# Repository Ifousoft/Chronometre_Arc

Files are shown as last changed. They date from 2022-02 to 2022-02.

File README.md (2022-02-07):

# Chronometre_Arc
Chronomètre de tir à l'arc

Ce chronomètre permet l’entraînement des archers à la compétition. Le chronomètre permet de choisir les équipes A/B ou C/D ainsi que de configurer les durées de pré-tir et de tir. Le chronomètre déclenche la sonnerie de pré-tir et de tir. La télécommande fournie avec le chronomètre permet de configurer les paramètres du chronomètre, de lancer le tir, de mettre le tir en pause ou de stopper le tir.
Les fichiers pour le code du chronomètre ainsi que la télécomande sont fournis.
Le modèle 3D pour le télécommande est également fourni au format Fusion 360.
Les plans électroniques pour la carte du chronomètre et celle de la télécommande sont fournis.

Coût d'environs 200 euros pour la partie électronique.

Le chronomètre est constitué de 3 écrans LED 64x32 pour avoir une des chiffres de 12 cm de haut. Les trois écrans sont installés verticalement.
Le chronomètre est piloté par un ESP32 et connecté à la télécommande en LoRa pour une grande portée.
La télécommande fonctionne avec un arduino nano et une puce LoRa.

Attention, erreur de conception, l'ampli est connecté sur une pate de l'esp32 qui n'est pas prévue pour passer un son mp3 ce qui rend impossible de jouer une musique.
Les sons pour démarrer ou stopper le tir ne sont donc pas très agréables.

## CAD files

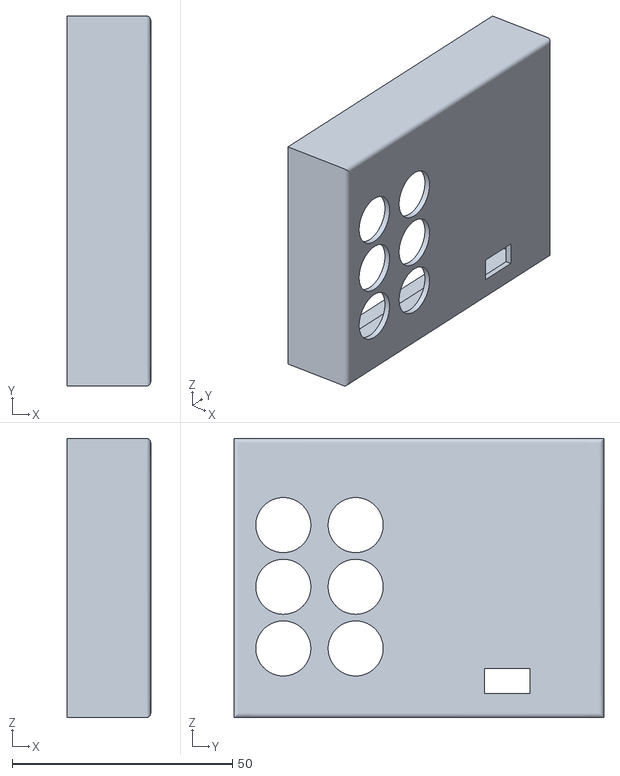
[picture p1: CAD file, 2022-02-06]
3D_models/Dessus.stl
19.0 x 84.0 x 63.4

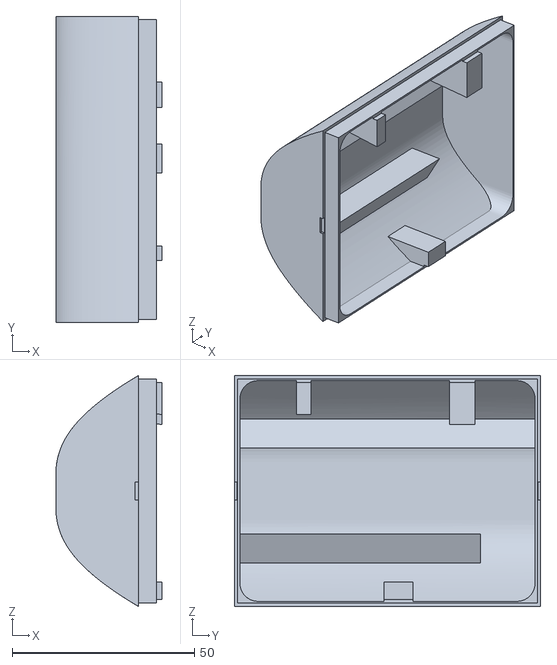
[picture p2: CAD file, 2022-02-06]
3D_models/Fond_V4.stl
29.2 x 84.0 x 63.4

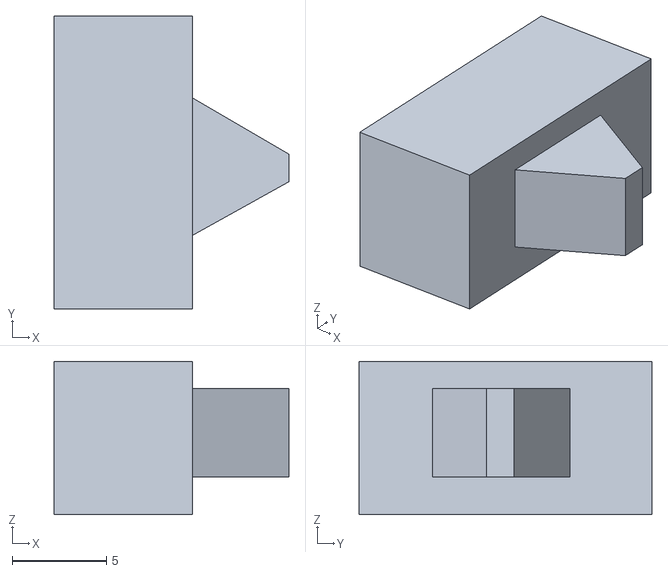
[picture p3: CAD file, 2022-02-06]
3D_models/Tirette.stl
12.5 x 15.6 x 8.15

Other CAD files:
3D_models/Telecomande_ARC_courbe v5.f3d

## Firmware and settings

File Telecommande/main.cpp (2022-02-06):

/*
Test Lora - Recepteur Télécommande ARC
06/10/2020
Heart beat: 39 mA
Sleep: 22,4 mA
Send Lora: 50 mA
Capacité pilr R6 2500 mA
Ecran OLED, serait en moyenne a 450 uA en fonctionnement
Antenne Lora en SPI (MISO/MOSI)

Voltage
3,27 bug
3,3 bug3,51 ok
3,55 bug

AFAIRE:
- Gestion de la batterie...
- Lorsque la télécommande se signale à l'écran: attendre un retour
- Est-ce nécessaire de réduire la vitesse du bus SPI ?
- Attendre un retour lors de l'envoie d'un message
- enableCRC
*/

/* PROTOCOLE
ENVOI DU BOUTON:
- Premier octet: numéro de l'émetteur (22 pour la télécommande ou 33 pour le heart beat de la télécommande)
- Deuxième octet: numéro du message cyclique de 0 à 7
- Troisième octet: numéro du bouton
ACK:
- premier octet: numéro de l'émetteur (22 ou 33)
- second octet: numéro du message reçu
HEART BEAT: Envoi périodique d'une pulsation à l'écran. En cas de problème l'écran affiche et la télécommande clignote
- premier octet: numéro de l'émetteur 33 pour heart beat
- second octet: numéro cyclique de 0 à 7

- Clignotement rapide LED power: low batt
*/

#define DEBUG // si défini = on affiche sur Serial, sinon riens

#include <Arduino.h>

#include <SPI.h>
#include <LoRa.h>
#include <avr/sleep.h>
#include <avr/power.h>
//#include <MsTimer2.h>
#include <avr/wdt.h>

#define SLEEP_PIN 3
#define FALSE  0
#define TRUE !FALSE

// Boutons ligne haut MOINS - SELECT - PLUS
// Boutons ligne bas START - STOP - PAUSE
#define PIN_BOUTON_PLUS A7 // Analogique
#define PIN_BOUTON_MOINS  8
#define PIN_BOUTON_SELECT 7

#define PIN_BOUTON_STOP 5
#define PIN_BOUTON_PAUSE  6     // Analogique
#define PIN_BOUTON_START  4


#define LED_LORA  A5 // Analogique
#define LED_POWER A2 // Analogique
#define PIN_VOLTAGE A0

#define VOLTAGE_LIMIT 3.3

// Attention, définition des boutons commun avec les recepteurs !
#define LORA_BOUTON_PLUS    1
#define LORA_BOUTON_MOINS   2
#define LORA_BOUTON_SELECT  3
#define LORA_BOUTON_INIT    4
#define LORA_BOUTON_STOP    5
#define LORA_BOUTON_PAUSE   6
#define LORA_BOUTON_START   7
#define LORA_HEART_BEAT     33  // Dites "33"...

#define ID_SENDER 22  // Pourquoi pas ?
#define ID_HEART_BEAT 33  // Pourquoi pas ?
#define NB_HEART_BEAT  4  // Nombre d'attente de 8 secondes de watchdog avant d'envoyer une pulsation

byte Id_Message = 0; // Sera incrémenté de 0 à 7
byte Id_Heart_Beat = 0;

byte Nb_Heart_Beat = NB_HEART_BEAT; 

byte Ack_Recu = FALSE;
byte Low_Batt = FALSE;

#define ATTENTE_ACK 3000  // Attente max pour un ACK en ms

// LORA pins
const int csPin = 10;          // 10 normalement 7 LoRa radio chip select
const int resetPin = 9;       // 5 d'après mon shéma... 6 LoRa radio reset
const int irqPin = 2;         // 1 DIO0 change for your board; must be a hardware interrupt pin

byte Bouton = 0;
unsigned int Rebond = 0;

void SendLoraMsg( byte bouton );
void InterruptionSendHeartBeat( void );

/********************************
 * watchdog interrupt
 * 
 * Appelé par le watchdog à la fin du timer
 * 
 * ******************************/
ISR (WDT_vect) 
{
   wdt_disable();  // disable watchdog

}  // end of WDT_vect

/********************************
 * SendHeartBeat
 * 
 * Envoi une pulsation à l'écran
 * 
 * ******************************/
void SendHeartBeat( void )
{
  SendLoraMsg( LORA_HEART_BEAT );
#ifdef DEBUG 
  Serial.println( "---- Hear Beat ----");
#endif
  analogWrite( LED_POWER, 255 );
  delay( 100 );
  analogWrite( LED_POWER, 0 );

} /* End of SendHeartBeat */

/******************************
 * WakeUp
 * 
 * Appellee en cas de reveil. Positionne Bouton à la valeur du bouton appuyé
 * 
 * *****************************/
void WakeUp( void )
{
  if( millis() + 100 > Rebond )
  {
    //Serial.print( "Reveil ");
    Bouton = 0;
    if( analogRead(PIN_BOUTON_PLUS) > 800  )
      Bouton = LORA_BOUTON_PLUS;
    else
    {
      if( digitalRead(PIN_BOUTON_MOINS) == 1 )
        Bouton = LORA_BOUTON_MOINS;
      else
      {
        if( digitalRead(PIN_BOUTON_SELECT) == 1 )
          Bouton = LORA_BOUTON_SELECT;
        else
        {
          if( digitalRead(PIN_BOUTON_STOP) == 1 )
            Bouton = LORA_BOUTON_STOP;
          else
          {
            if( digitalRead( PIN_BOUTON_START) == 1 )
              Bouton = LORA_BOUTON_START;
            else
            {
              if( digitalRead( PIN_BOUTON_PAUSE ) == 1 )
                Bouton = LORA_BOUTON_PAUSE;
            } /* End of if */           
          } /* End of if */
        } /* End of if */
      } /* End of if */
    } /* End of if */

#ifdef DEBUG
    if( Bouton != 0 )
    {
      Serial.print( "****** Bouton =" );
      Serial.println( Bouton );
    } /* End of if */
#endif
    Rebond = millis();
  } /* End of if */

} /* End of WakeUp */

/**************************************
 * RecoitAck
 * 
 * Call back en cas de reception de la part de l'écran: ACK ou HEART BEAT
 * 
 * Positionne une variable globale si ACK et/ou si HEART BEAT
 * 
 * ***************************************/
void RecoitAck(int packetSize)
{
  if (packetSize == 2)
  {
    byte id_sender_back;
    byte id_message_back;

    id_sender_back = LoRa.read();
    id_message_back = LoRa.read();

    if( id_sender_back == ID_SENDER && id_message_back == Id_Message )
    {
      Ack_Recu = TRUE;
      Id_Message = (Id_Message +1 ) % 8;
#ifdef DEBUG
      Serial.println( "ACK correct recu ............");
#endif
      analogWrite( LED_LORA, 1024 );
      delay( 50 );
      analogWrite( LED_LORA, 0 );
    }
#ifdef DEBUG
    else
    {
      Serial.println( "ERREUR - ACK correct mais pour un mauvais message ");
    }
#endif  
  }
#ifdef DEBUG
  else
  {
    Serial.println( "ERREUR - ACK de taille incorrecte ");
  }
#endif  
} /* End of RecoitAck */

/****************************
 * 
 * SendLoraMsg
 * 
 * Envoie le message en LORA et attend le ACK
 * 
 * *************************/
void SendLoraMsg( byte bouton )
{
  LoRa.beginPacket();
  LoRa.write( ID_SENDER );
  LoRa.write( Id_Message );
  LoRa.write( bouton );
  LoRa.endPacket();
#ifdef DEBUG
  Serial.print( "LoRa sent: ");
  Serial.println( bouton );
#endif
  analogWrite( LED_LORA, 1024 );
  delay( 50 );
  analogWrite( LED_LORA, 0 );

} /* End of SendLoraMsg */

/************************
 * InitTelecommandeVersEcran
 * 
 * Signale la télécommande à l'écran
 * 
 * **************************/
void InitTelecommandeVersEcran( void )
{
  SendLoraMsg( LORA_BOUTON_INIT );
  analogWrite( LED_POWER, 1024 );
  delay( 100 );
  analogWrite( LED_POWER, 0 );
  delay( 100 );
  analogWrite( LED_POWER, 1024 );
  delay( 100 );
  analogWrite( LED_POWER, 0 );

} /* End of InitTelecommandeVersEcran */

/*******************************
 * StartLoRa
 * 
 * Démarre ou reveille la puce lora pour préparer la transmission
 * 
 * *****************************/
void StartLoRa( void )
{
#ifdef DEBUG
  Serial.println("*********** Debut LORA Begin");
#endif
  while( !LoRa.begin(868E6) )
  {
#ifdef DEBUG
    Serial.println("Starting LoRa...");
#endif
    delay( 500 );
  }
#ifdef DEBUG
  Serial.println(" LORA Begin success");
#endif

} /* End of StartLoRa */

/******************************
 * SetWatchDog
 * 
 * Arme un timer de 8 secondes maximum pour le reveiller
 * 
 * *****************************/
void SetWatchDog( void )
{
  // WatchDog toutes les 8 secondes
    // clear various "reset" flags
  MCUSR = 0;     
  // allow changes, disable reset
  WDTCSR = bit (WDCE) | bit (WDE);
  // set interrupt mode and an interval 
  WDTCSR = bit (WDIE) | bit (WDP3) | bit (WDP0);    // set WDIE, and 8 seconds delay
  wdt_reset();  // pat the dog

} /* End of SetWatchDog */

/***************************
 * setup
 * 
 * *************************/
void setup( void ) {

#ifdef DEBUG
  Serial.begin(115200);
  Serial.println(" Démarrage.");
#endif
  pinMode( PIN_BOUTON_PLUS, INPUT );
  pinMode( PIN_BOUTON_MOINS, INPUT );
  pinMode( PIN_BOUTON_SELECT, INPUT );
  pinMode( PIN_BOUTON_STOP, INPUT );
  pinMode( PIN_BOUTON_START, INPUT );
  pinMode( PIN_BOUTON_PAUSE, INPUT );
  pinMode( PIN_VOLTAGE, INPUT );

  pinMode( LED_LORA, OUTPUT );
  pinMode( LED_POWER, OUTPUT );

  for( byte i = 0 ; i < 5 ; i ++ )
  {
    analogWrite( LED_LORA, 1024 );
    delay( 150 );
    analogWrite( LED_LORA, 0 );
    delay( 150 );
  }

  // Sleep
  // Serial.end();
  pinMode( SLEEP_PIN, INPUT);
  sleep_enable();
//  power_adc_disable();
//  power_spi_disable(); Utile pour LORA
// power_timer0_disable();
// power_timer1_disable();
 power_timer2_disable();
  attachInterrupt(1, WakeUp, HIGH); // Reveil sur la pate 4 (Interuption 1)
  set_sleep_mode (SLEEP_MODE_STANDBY);
//  set_sleep_mode (SLEEP_MODE_PWR_DOWN);

#ifdef DEBUG
  Serial.println("LoRa Sender");
#endif
  LoRa.setPins(csPin, resetPin, irqPin);// set CS, reset, IRQ pin
  LoRa.setSPIFrequency(1E6); // Ajout IFOU

  StartLoRa();

  LoRa.onReceive( RecoitAck );
  LoRa.receive();

  SetWatchDog();

  InitTelecommandeVersEcran();

} /* End of setup */

/**********************
 * BlynkBatt
 * 
 * Fait clignoter la LED power
 * 
 * *********************/
void BlynkBatt( void )
{
  for( byte i = 0 ; i < 5 ; i ++)
  {
    digitalWrite( LED_POWER, HIGH );
    delay(50);
    digitalWrite( LED_POWER, LOW );
    delay(50);
  } /* End of for */

} /* End of BlynkBatt */

/**************************
 * 
 * loop
 * 
 * *************************/
void loop() {

#ifdef DEBUG
  Serial.println( "Sleep activé");
  Serial.flush();
#endif
  LoRa.sleep();
  delay( 100 );
  sleep_cpu ();
#ifdef DEBUG
  Serial.println( "WakeUp");
#endif  
  // Au reveil, on s'annonce toujours vivant
  if( --Nb_Heart_Beat == 0 )
  {
    SendHeartBeat();
    Nb_Heart_Beat = NB_HEART_BEAT;
  } /* End of if */

  if( Bouton != 0)
    SendLoraMsg( Bouton );

#ifdef DEBUG
  Serial.print( "Voltage = ");
  Serial.println( analogRead( PIN_VOLTAGE ));
  float batt_level = analogRead( PIN_VOLTAGE )/1024.0*3.7;
  Serial.println( batt_level );
#endif
  if( batt_level < VOLTAGE_LIMIT )
    Low_Batt = TRUE;

  if( Low_Batt )
    BlynkBatt();

  LoRa.receive();
  //delay(1500);

  // On réarme le watchDog avant de se réendormir
  SetWatchDog();

} /* End of loop */

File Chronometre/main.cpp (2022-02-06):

// Chrono Arc V4 - LoRa
// 5 septembre Initialisation 2019
// 4 octobre réduction des chiffres pour passer sur 3 écrans avec 240 au max
// 29 novembre:
//    - affichage logo lora (bluetooth) en attente de télécommande
//    - On peut plus faire start qd on est en cours de chrono
//    - affichage de perte et de retour de télécommande
// 5 janvier 2021 - ajout de la possibilité d'utiliser les écrans extérieurs. Ca marche !
// 6 janvier 2021 - Ajout d'un flush après réception pour éviter les parasites
// 7 janvier 2021 - Ajout de la gestion de la luminosité pour écran extérieur (même pour int même si ca fait rien)
// 23 janvier 2021 - Réduction du nombre de raffraichissement pour accelerer affichage
// 6 décembre 2021 - Suppression du bruit parasite généré par l'initialisation de l'écran LED. Pas compris...
// 7 décembre 2021 - Impossible de lancer un Wav, il faudrait que les HP soient branchés sur le DAC pin 25 ou 26...
// 8 décembre 2021 - Affichage logo IfouSoft et Logo companie
// 10 décembre 2021 - Affichage du temps de tir avant la volée au lieu de la durée de pre-tir
//                  - Ajout d'une phase de PRE_VOLEE 

// A FAIRE
// Test de tout les éléments d'affichages au démarrage
// Le HP grésille légèrement (Qualité montage ?)
//    Mettre à bas le signal au démarrage ?
// Virer Blynk et remplacer ses timers
// Changer la couleur du pretir pour identifier la différence TIR/Pretir
//    Jean-Philippe ?
// Afficher logo de l'abbaye au démarrage ?

/*
A Faire:
P2 - Quand la télécommande est alluméé avant l'écran, un appuie sur un bouton devrait la faire reconnaitre par l'écran sans attendre le HeartBeat
- Reglable de la luminosité
P2 - descendre le defaut telecommande d'un cran
- Ajouter affichage indication pb batteries sur écran
- Afficher la durée du tir et non du prétir au démarrage
*/

// Choisir entre compiler pour écran intérieurs ou écran extérieur. Exclusifs
//#define ECRAN_INT   // Pour les écrans intérieurs utilisant la library EPS32 64x32 LED MATRIX HUB75 DMA Display
#define ECRAN_EXT   // Pour les ecran extérieurs ayant besoin de la library SmartMatrix pour remapper les lignes

#define VERSION "V4.0"


#include <Arduino.h>
#include <Wire.h>
#include <SPI.h>
#ifdef ECRAN_INT
#include <ESP32-RGB64x32MatrixPanel-I2S-DMA.h>
#else
#include <MatrixHardware_ESP32_V0.h>                // This file contains multiple ESP32 hardware configurations, edit the file to define GPIOPINOUT (or add #define GPIOPINOUT with a hardcoded number before this #include)
#include <SmartMatrix.h>
#endif
#include <BlynkSimpleEsp32_BT.h>
#include <Tone32.h>
#include "SPIFFS.h"

//#include "Abbaye.c"
#include "A1.c"
#include "A3.c"
#include "A2.c"
#include "Logo.ifou.c"

#define BUZZER_PIN 4 // 14 initialement mais changer et mettre ?
#define BUZZER_CHANNEL 0


#define DUREE_SECONDE 1000  // 1 seconde = 1000 ms
#define DUREE_AFFICHAGE_LOGO_IFOU 5000
#define DUREE_AFFICHAGE_LOGO_CIE 10000



#define BLYNK_USE_DIRECT_CONNECT

char auth[] = "y6KFaS2UmRR15rvGpoEeqGNoRn9UKU3E"; // Code de l'application Blynk

#ifdef ECRAN_INT
RGB64x32MatrixPanel_I2S_DMA dma_display;

#define COULEUR_ROUGE dma_display.color444(15, 0, 0)
#define COULEUR_VERT  dma_display.color444(0, 15, 0)
#define COULEUR_BLEU  dma_display.color444(0, 0, 15)
#define COULEUR_NOIR  dma_display.color444(0, 0, 0)
#define COULEUR_BLANC dma_display.color444(15, 15, 15)
#define COULEUR_ORANGE  dma_display.color444(15, 9, 0)
#define COULEUR_IFOU  dma_display.color444(2, 2, 7)
#define COULEUR_JAUNE  dma_display.color444(15, 15, 0)
#else
#define COLOR_DEPTH 24                  // known working: 24, 48 - If the sketch uses type `rgb24` directly, COLOR_DEPTH must be 24

const uint8_t kMatrixWidth = 192;        // 32 known working: 16, 32, 48, 64
const uint8_t kMatrixHeight = 32;       // 16 known working: 32, 64, 96, 128
const uint8_t kPanelType = SM_PANELTYPE_HUB75_32ROW_64COL_MOD8SCAN_IFOU;   // use SMARTMATRIX_HUB75_16ROW_MOD8SCAN for common 16x32 panels
const uint8_t kRefreshDepth = 36;       // known working: 24, 36, 48
const uint8_t kDmaBufferRows = 4;       // known working: 2-4, use 2 to save memory, more to keep from dropping frames and automatically lowering refresh rate
const uint8_t kMatrixOptions = (SMARTMATRIX_OPTIONS_NONE);      // see http://docs.pixelmatix.com/SmartMatrix for options
const uint8_t kBackgroundLayerOptions = (SM_BACKGROUND_OPTIONS_NONE);
const uint8_t kIndexedLayerOptions = (SM_INDEXED_OPTIONS_NONE);

const rgb24 COULEUR_NOIR = { 0, 0, 0 };
const rgb24 COULEUR_BLANC = { 255, 255, 255 };
const rgb24 COULEUR_ROUGE = { 255, 0, 0 };
const rgb24 COULEUR_VERT = { 0, 255, 0 };
const rgb24 COULEUR_BLEU = { 0, 0, 255 };
const rgb24 COULEUR_ORANGE = { 255, 165, 0 };
const rgb24 COULEUR_JAUNE = { 255, 255, 0 };
const rgb24 COULEUR_IFOU = { 34, 34, 127 };

SMARTMATRIX_ALLOCATE_BUFFERS(matrix, kMatrixWidth, kMatrixHeight, kRefreshDepth, kDmaBufferRows, kPanelType, kMatrixOptions);
SMARTMATRIX_ALLOCATE_BACKGROUND_LAYER(backgroundLayer, kMatrixWidth, kMatrixHeight, COLOR_DEPTH, kBackgroundLayerOptions);
SMARTMATRIX_ALLOCATE_INDEXED_LAYER(indexedLayer, kMatrixWidth, kMatrixHeight, COLOR_DEPTH, kIndexedLayerOptions);
#endif

#define X_CHIFFRE_CENTAINES 0
#define X_CHIFFRE_DIZAINES  64
#define X_CHIFFRE_UNITES    128
#define Y_CHIFFRE           2

#define OFF 0
#define ON  1

#define DUREE_TIR_DEFAULT     120
#define DUREE_PRETIR_DEFAULT  20
#define DUREE_ORANGE          30

byte Duree_Pre_Tir = DUREE_PRETIR_DEFAULT;
byte Duree_Tir = DUREE_TIR_DEFAULT;

// Ecran LCD 64x32
// 3 écrans verticaux
// Largeur: 16 pour Feux, 16 pour centaine du compteur, 32 pour dizaine du compteur, 32 pour unités du compteur
// Hauteur 64
#define FEUX_X        43
#define FEU_ROUGE_Y   2
#define FEU_ORANGE_Y  2
#define FEU_VERT_Y    2
#define FEU_BLEU_Y    2 // Feu de configuration
#define FEUX_HAUTEUR  20
#define FEUX_LARGEUR  28

#define EQUIPE_AB 0
#define EQUIPE_CD !EQUIPE_AB

#define FALSE 0
#define TRUE  !FALSE

// Phases de tir
#define P_STOP    0
#define P_PRE_TIR 1
#define P_TIR     2
#define P_PAUSE_TIR 3
#define P_PAUSE_PRE_TIR 4
#define P_PRE_VOLEE 5

#define INTERVAL_SIGNAL_SONORE 1000 // 1 seconde

SimpleTimer Timer_Chrono;
byte Decompte = 0;
byte Phase = P_STOP; // Différentes phases de tir, prétir, stop, pause...
int Timer_Chrono_No;
byte Feu_Rouge = OFF;
byte Feu_Orange = OFF;
byte Feu_Vert = OFF;
byte Feu_Configuration = OFF;
byte Equipe_en_Cours = EQUIPE_AB;
byte Feux_A_Rafraichir = FALSE;
byte Chrono_A_Rafraichir = FALSE;
byte Son_A_Delivrer = 0;
int Freq_Son = 270;
int Duree_Son = 750;
extern byte Telecommande_Connectee;
byte Luminosite = 0; // de 0 à 3

enum { SELECT_VIDE=0, SELECT_PRETIR, SELECT_TIR, SELECT_EQUIPE, SELECT_LUMINOSITE };
byte ElementSelected = SELECT_VIDE;
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
